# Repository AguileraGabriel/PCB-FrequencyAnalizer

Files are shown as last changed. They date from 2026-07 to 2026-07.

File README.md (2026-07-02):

# TD3-FrequencyAnalizer

Proyecto de KiCad para el Analizador de Frecuencias (TD3).

## Descripción del Proyecto

Este es un proyecto de diseño de PCB desarrollado en KiCad 10.0.4.

## Estructura del Proyecto

*   **`TD3-FrequencyAnalizer.kicad_pro`**: Archivo de proyecto de KiCad.
*   **`TD3-FrequencyAnalizer.kicad_sch`**: Esquema del circuito.
*   **`TD3-FrequencyAnalizer.kicad_pcb`**: Diseño del circuito impreso (PCB).
*   **`.gitignore`**: Exclusiones de Git para evitar subir archivos temporales y copias de seguridad de KiCad.

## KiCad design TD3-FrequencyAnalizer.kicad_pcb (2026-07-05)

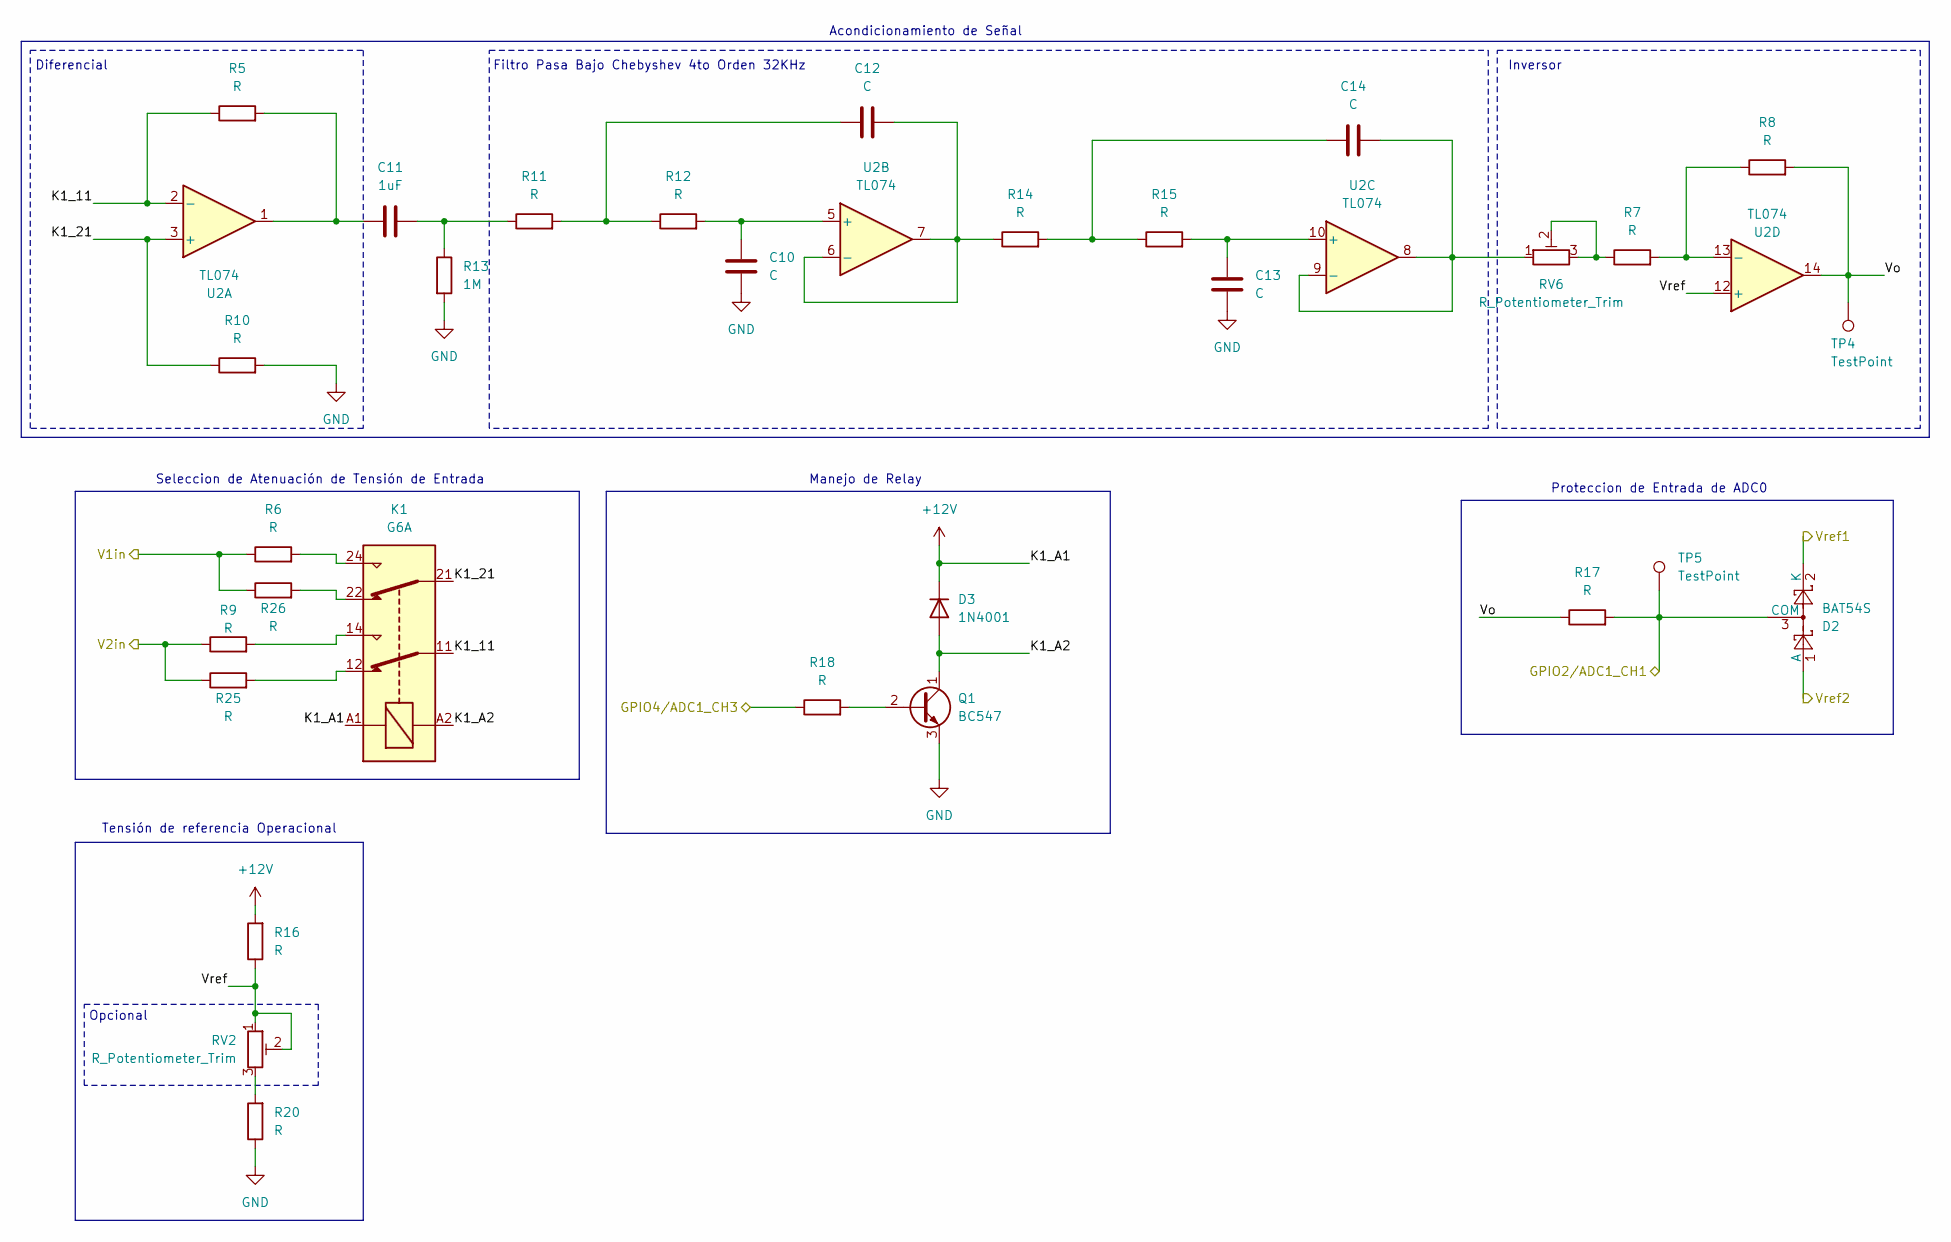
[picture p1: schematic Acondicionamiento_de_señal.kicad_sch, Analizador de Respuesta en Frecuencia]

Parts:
C10, C12, C13, C14: C; C_Disc_D7.5mm_W2.5mm_P5.00mm
C11: 1uF; C_Disc_D7.5mm_W2.5mm_P5.00mm
D2: BAT54S; SOT-23
D3: 1N4001; D_DO-41_SOD81_P10.16mm_Horizontal
K1: G6A; Relay_DPDT_Omron_G6A
Q1: BC547; TO-92_HandSolder
R5, R6, R7, R8, R9, R10, R11, R12, R14, R15, R16, R17, R18, R20, R25, R26: R; R_Axial_DIN0207_L6.3mm_D2.5mm_P10.16mm_Horizontal
R13: 1M; R_Axial_DIN0207_L6.3mm_D2.5mm_P10.16mm_Horizontal
RV2, RV6: R_Potentiometer_Trim; Potentiometer_Bourns_3266Y_Vertical
TP4, TP5: TestPoint; TestPoint_Loop_D2.50mm_Drill1.0mm
U2: TL074; CERDIP-14_W7.62mm_SideBrazed_LongPads_Socket

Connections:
+12V: D3.1 (K), K1.A1, R16.2; also elsewhere on the board
/Acondicionamiento de Señal de Entrada/GPIO2/ADC1_CH1: D2.3 (COM), R17.2, TP5.1 (1_1); also elsewhere on the board
/Acondicionamiento de Señal de Entrada/GPIO4/ADC1_CH3: R18.1; also elsewhere on the board
/Acondicionamiento de Señal de Entrada/K1_11: K1.11, R5.1, U2.2 (-)
/Acondicionamiento de Señal de Entrada/K1_21: K1.21, R10.1, U2.3 (+)
/Acondicionamiento de Señal de Entrada/K1_A2: D3.2 (A), K1.A2, Q1.1 (C)
/Acondicionamiento de Señal de Entrada/V1in: R6.1, R26.1; also elsewhere on the board
/Acondicionamiento de Señal de Entrada/V2in: R9.1, R25.1; also elsewhere on the board
/Acondicionamiento de Señal de Entrada/Vo: R8.2, R17.1, TP4.1 (1_1), U2.14
/Acondicionamiento de Señal de Entrada/Vref: R16.1, RV2.1, RV2.2, U2.12 (+)
/Acondicionamiento de Señal de Entrada/Vref1: D2.2 (K); also elsewhere on the board
/Acondicionamiento de Señal de Entrada/Vref2: D2.1 (A); also elsewhere on the board
GND: C10.2, C13.2, Q1.3 (E), R10.2, R13.2, R20.1; also elsewhere on the board
unnamed: C11.1, R5.2, U2.1
unnamed: C11.2, R11.1, R13.1
unnamed: C12.1, R11.2, R12.1
unnamed: C14.1, R14.2, R15.1
unnamed: K1.12, R25.2
unnamed: K1.14, R9.2
unnamed: K1.22, R26.2
unnamed: K1.24, R6.2
unnamed: Q1.2 (B), R18.2
unnamed: R7.1, RV6.2, RV6.3
unnamed: R20.2, RV2.3
unnamed: C10.1, R12.2, U2.5 (+)
unnamed: C12.2, R14.1, U2.6 (-), U2.7
unnamed: C13.1, R15.2, U2.10 (+)
unnamed: C14.2, RV6.1, U2.8, U2.9 (-)
unnamed: R7.2, R8.1, U2.13 (-)

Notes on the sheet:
Manejo de Relay
Opcional
Filtro Pasa Bajo Chebyshev 4to Orden 32KHz
Acondicionamiento de Señal
Seleccion de Atenuación de Tensión de Entrada
Diferencial
Tensión de referencia Operacional
Proteccion de Entrada de ADC0
Inversor

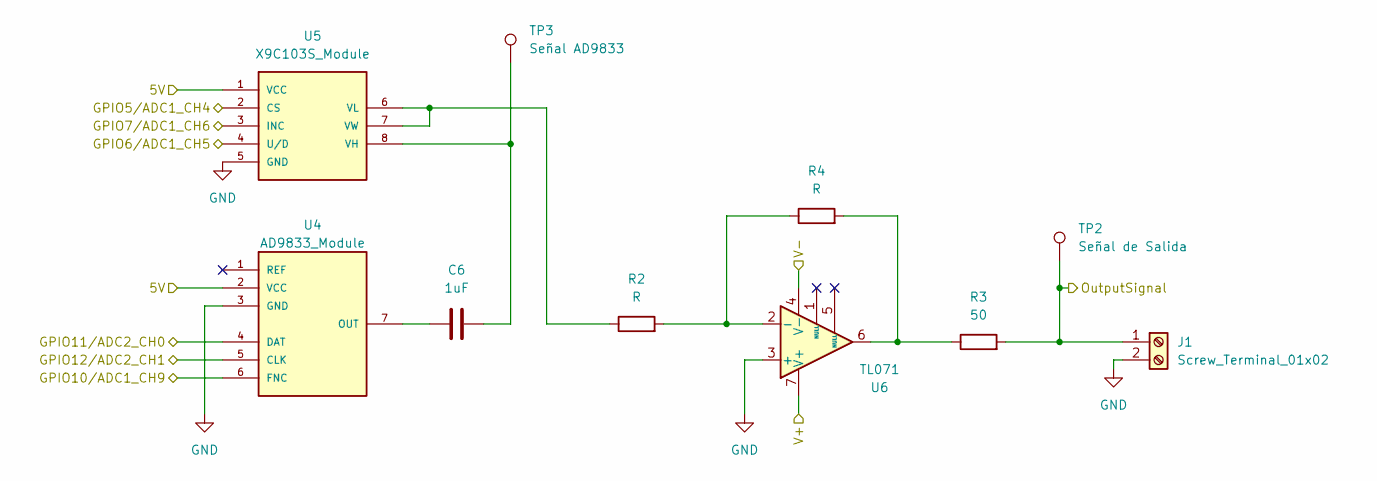
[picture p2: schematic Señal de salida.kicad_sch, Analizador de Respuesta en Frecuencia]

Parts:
C6: 1uF; C_Disc_D7.5mm_W2.5mm_P5.00mm
J1: Screw_Terminal_01x02; TerminalBlock_MaiXu_MX126-5.0-02P_1x02_P5.00mm
R2, R4: R; R_Axial_DIN0207_L6.3mm_D2.5mm_P10.16mm_Horizontal
R3: 50; R_Axial_DIN0207_L6.3mm_D2.5mm_P10.16mm_Horizontal
TP2: Señal de Salida; TestPoint_Loop_D2.50mm_Drill1.0mm
TP3: Señal AD9833; TestPoint_Loop_D2.50mm_Drill1.0mm
U4: AD9833_Module
U5: X9C103S_Module
U6: TL071; CERDIP-8_W7.62mm_SideBrazed_LongPads_Socket

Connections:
+12V: U6.7 (V+); also elsewhere on the board
-12V: U6.4 (V-); also elsewhere on the board
/ESP32-S3/5V: U4.2 (VCC), U5.1 (VCC); also elsewhere on the board
/ESP32-S3/GPIO5/ADC1_CH4: U5.2 (CS); also elsewhere on the board
/ESP32-S3/GPIO6/ADC1_CH5: U5.4 (U/D); also elsewhere on the board
/ESP32-S3/GPIO7/ADC1_CH6: U5.3 (INC); also elsewhere on the board
/ESP32-S3/GPIO10/ADC1_CH9: U4.6 (FNC); also elsewhere on the board
/ESP32-S3/GPIO11/ADC2_CH0: U4.4 (DAT); also elsewhere on the board
/ESP32-S3/GPIO12/ADC2_CH1: U4.5 (CLK); also elsewhere on the board
/Medición de Señal Inyectada/OutputSignal: J1.1, R3.2, TP2.1 (1_1); also elsewhere on the board
GND: J1.2, U4.3 (GND), U5.5 (GND), U6.3 (+); also elsewhere on the board
unnamed: R3.1, R4.2, U6.6
unnamed: C6.1, U4.7 (OUT)
unnamed: C6.2, TP3.1 (1_1), U5.8 (VH)
unnamed: R2.1, U5.6 (VL), U5.7 (VW)
unnamed: R2.2, R4.1, U6.2 (-)

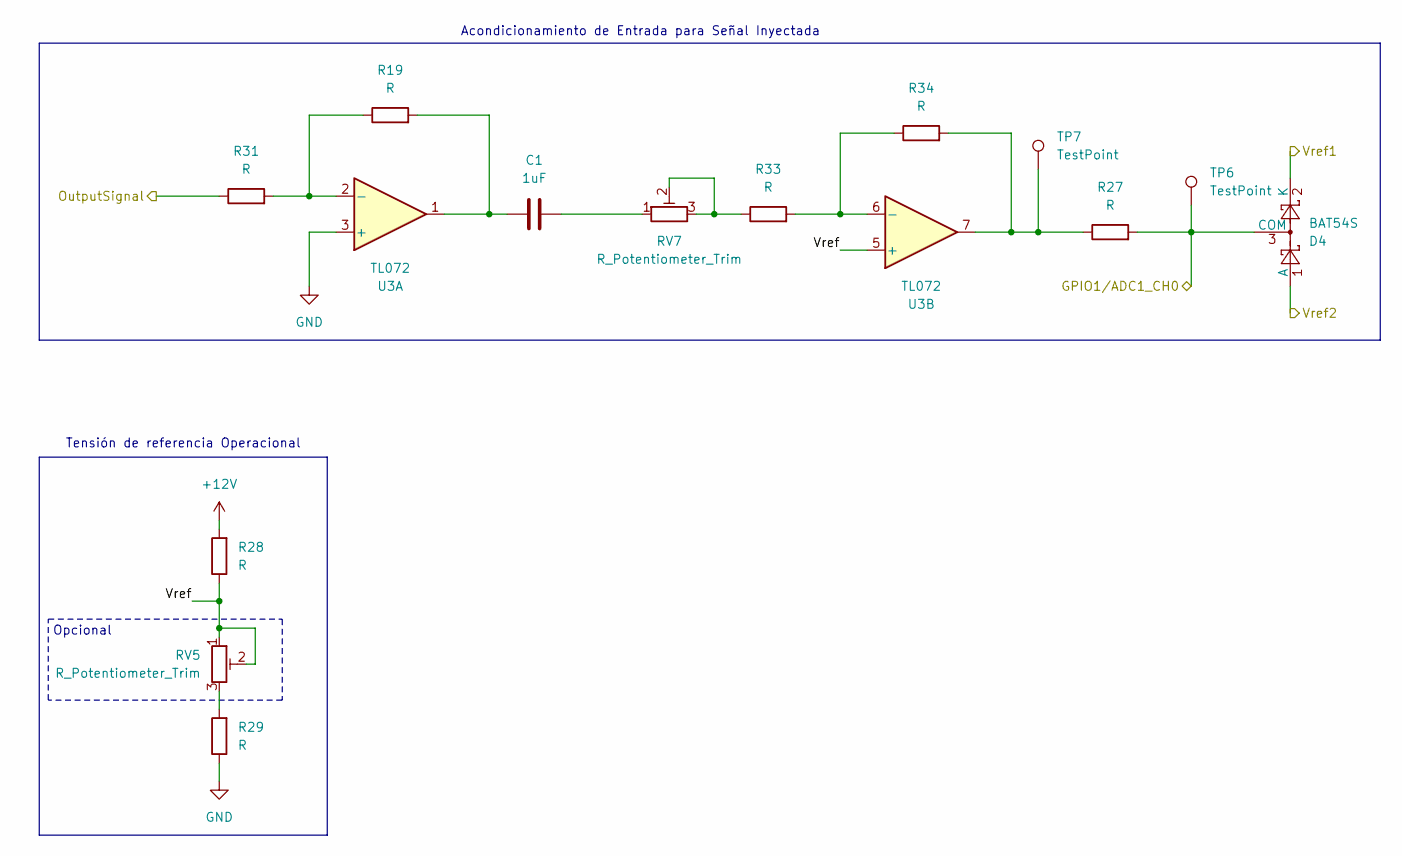
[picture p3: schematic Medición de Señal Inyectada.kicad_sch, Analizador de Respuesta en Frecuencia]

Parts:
C1: 1uF; C_Disc_D7.5mm_W2.5mm_P5.00mm
D4: BAT54S; SOT-23
R19, R27, R28, R29, R31, R33, R34: R; R_Axial_DIN0207_L6.3mm_D2.5mm_P10.16mm_Horizontal
RV5, RV7: R_Potentiometer_Trim; Potentiometer_Bourns_3266Y_Vertical
TP6, TP7: TestPoint; TestPoint_Loop_D2.50mm_Drill1.0mm
U3: TL072; CERDIP-8_W7.62mm_SideBrazed_LongPads_Socket

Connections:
+12V: R28.2; also elsewhere on the board
/Acondicionamiento de Señal de Entrada/Vref1: D4.2 (K); also elsewhere on the board
/Acondicionamiento de Señal de Entrada/Vref2: D4.1 (A); also elsewhere on the board
/ESP32-S3/GPIO1/ADC1_CH0: D4.3 (COM), R27.2, TP6.1 (1_1); also elsewhere on the board
/Medición de Señal Inyectada/OutputSignal: R31.1; also elsewhere on the board
/Medición de Señal Inyectada/Vref: R28.1, RV5.1, RV5.2, U3.5 (+)
GND: R29.1, U3.3 (+); also elsewhere on the board
unnamed: C1.1, R19.2, U3.1
unnamed: C1.2, RV7.1
unnamed: R27.1, R34.2, TP7.1 (1_1), U3.7
unnamed: R29.2, RV5.3
unnamed: R33.1, RV7.2, RV7.3
unnamed: R19.1, R31.2, U3.2 (-)
unnamed: R33.2, R34.1, U3.6 (-)

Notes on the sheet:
Opcional
Acondicionamiento de Entrada para Señal Inyectada
Tensión de referencia Operacional

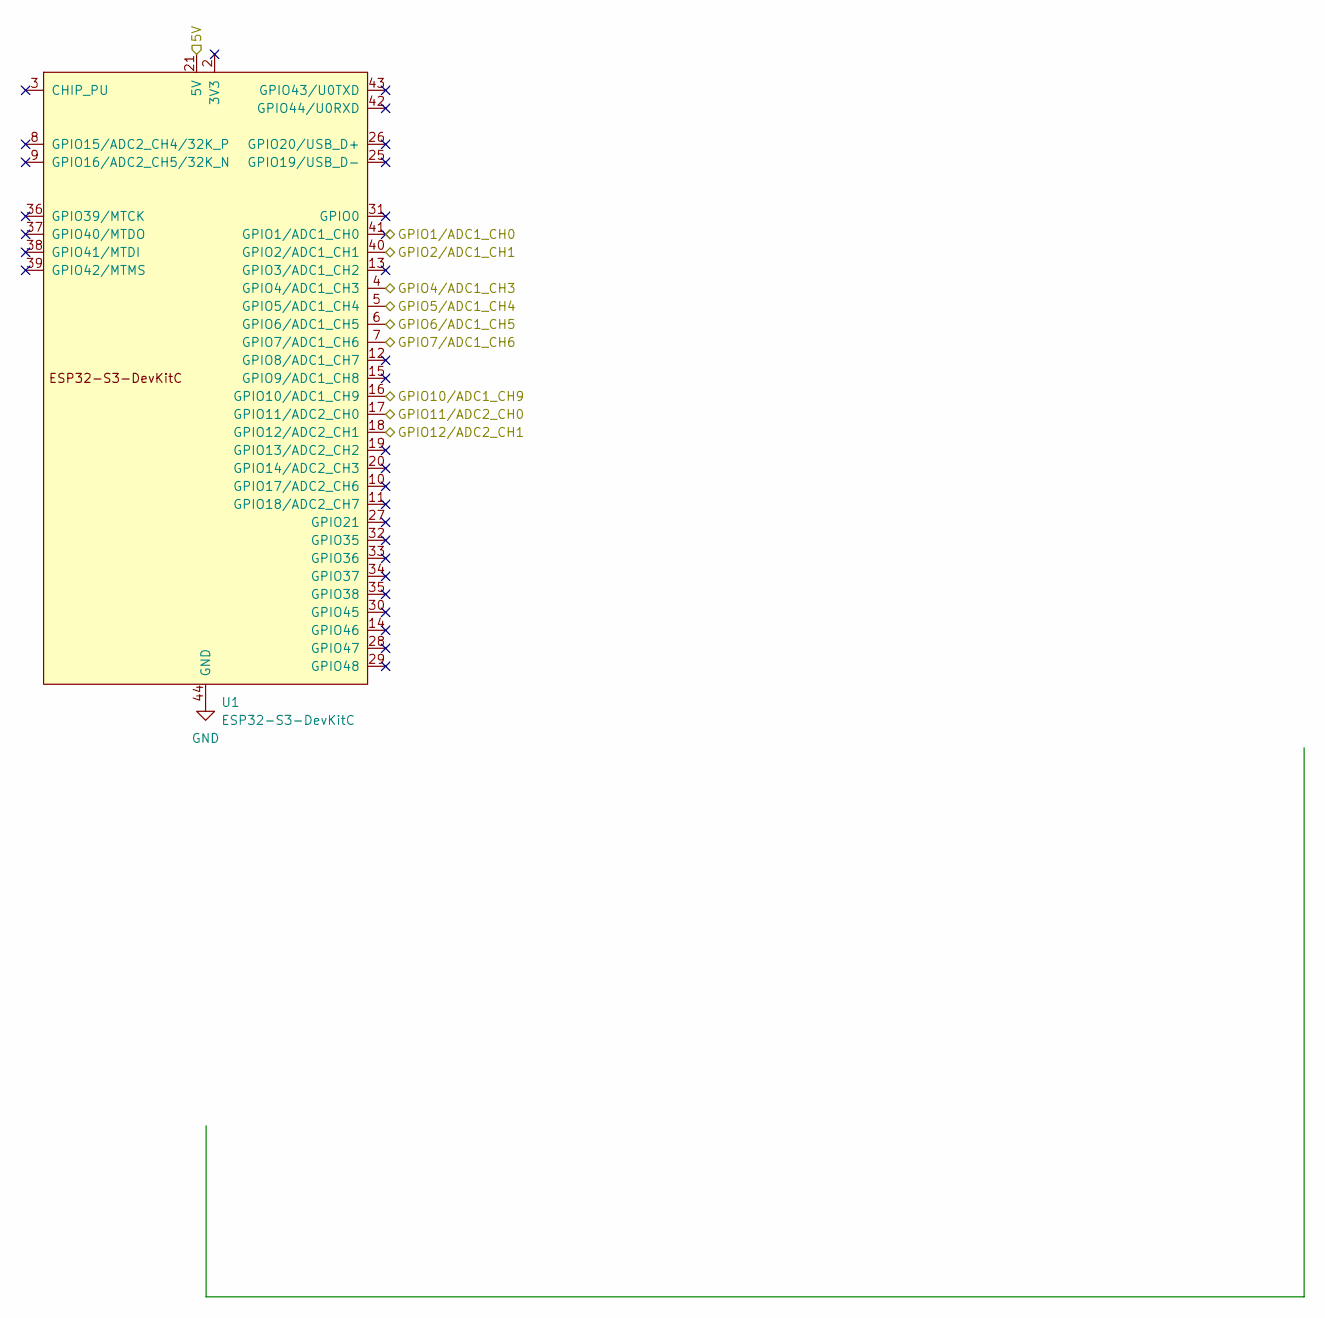
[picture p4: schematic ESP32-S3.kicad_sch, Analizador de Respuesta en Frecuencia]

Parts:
U1: ESP32-S3-DevKitC

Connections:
/Acondicionamiento de Señal de Entrada/GPIO2/ADC1_CH1: U1.40 (GPIO2/ADC1_CH1); also elsewhere on the board
/Acondicionamiento de Señal de Entrada/GPIO4/ADC1_CH3: U1.4 (GPIO4/ADC1_CH3); also elsewhere on the board
/ESP32-S3/5V: U1.21 (5V); also elsewhere on the board
/ESP32-S3/GPIO1/ADC1_CH0: U1.41 (GPIO1/ADC1_CH0); also elsewhere on the board
/ESP32-S3/GPIO5/ADC1_CH4: U1.5 (GPIO5/ADC1_CH4); also elsewhere on the board
/ESP32-S3/GPIO6/ADC1_CH5: U1.6 (GPIO6/ADC1_CH5); also elsewhere on the board
/ESP32-S3/GPIO7/ADC1_CH6: U1.7 (GPIO7/ADC1_CH6); also elsewhere on the board
/ESP32-S3/GPIO10/ADC1_CH9: U1.16 (GPIO10/ADC1_CH9); also elsewhere on the board
/ESP32-S3/GPIO11/ADC2_CH0: U1.17 (GPIO11/ADC2_CH0); also elsewhere on the board
/ESP32-S3/GPIO12/ADC2_CH1: U1.18 (GPIO12/ADC2_CH1); also elsewhere on the board
GND: U1.22 (GND), U1.23 (GND), U1.24 (GND), U1.44 (GND); also elsewhere on the board

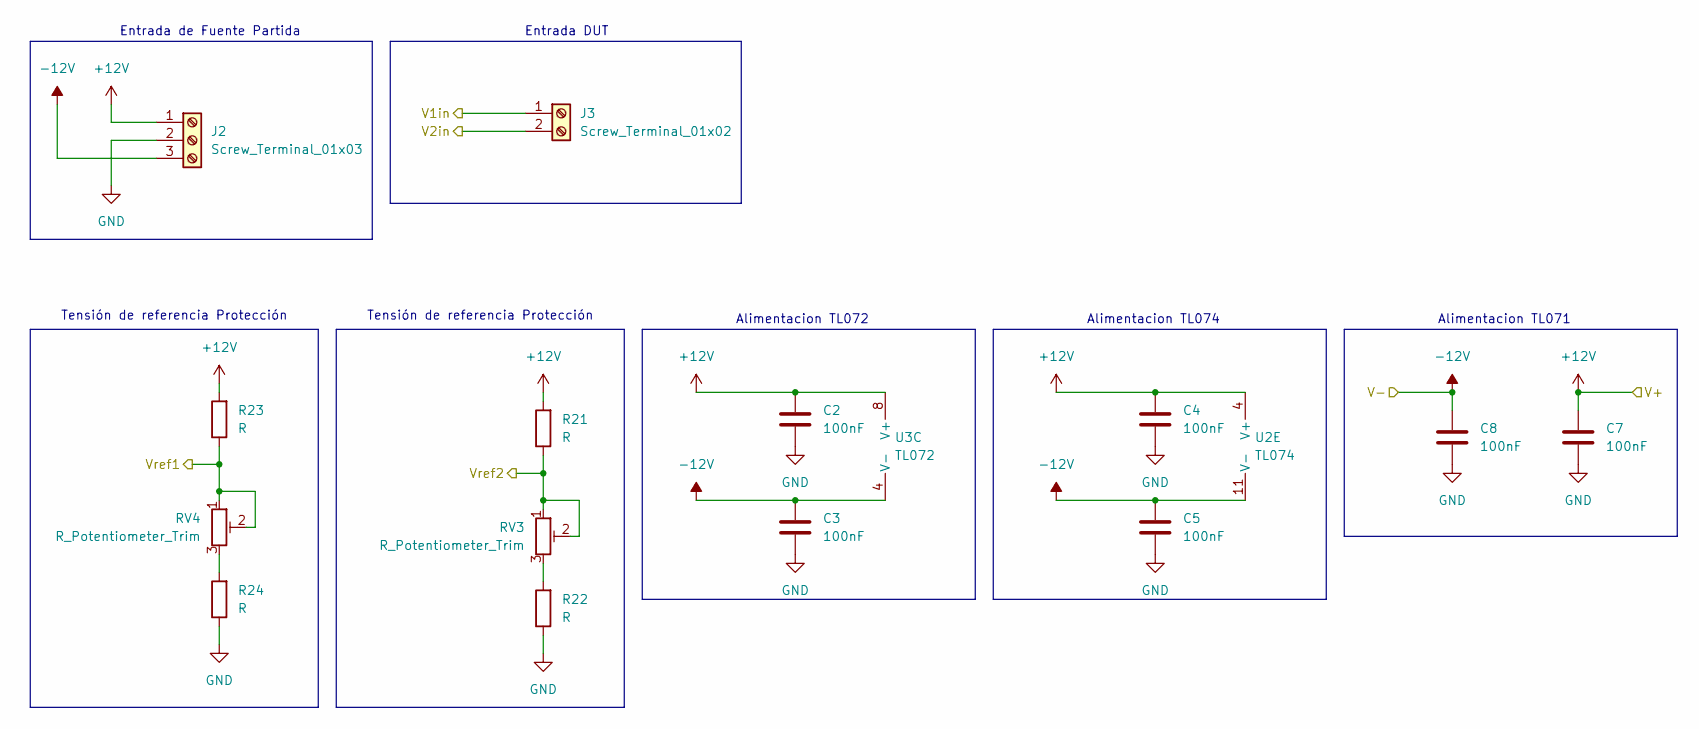
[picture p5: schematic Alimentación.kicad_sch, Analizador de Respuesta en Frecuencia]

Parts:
C2, C3, C4, C5, C7, C8: 100nF; C_Disc_D7.5mm_W2.5mm_P5.00mm
J2: Screw_Terminal_01x03; TerminalBlock_MaiXu_MX126-5.0-03P_1x03_P5.00mm
J3: Screw_Terminal_01x02; TerminalBlock_MaiXu_MX126-5.0-02P_1x02_P5.00mm
R21, R22, R23, R24: R; R_Axial_DIN0207_L6.3mm_D2.5mm_P10.16mm_Horizontal
RV3, RV4: R_Potentiometer_Trim; Potentiometer_Bourns_3266Y_Vertical
U2: TL074; CERDIP-14_W7.62mm_SideBrazed_LongPads_Socket
U3: TL072; CERDIP-8_W7.62mm_SideBrazed_LongPads_Socket

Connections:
+12V: C2.1, C4.1, C7.2, J2.1, R21.2, R23.2, U2.4 (V+), U3.8 (V+); also elsewhere on the board
-12V: C3.1, C5.1, C8.2, J2.3, U2.11 (V-), U3.4 (V-); also elsewhere on the board
/Acondicionamiento de Señal de Entrada/V1in: J3.1; also elsewhere on the board
/Acondicionamiento de Señal de Entrada/V2in: J3.2; also elsewhere on the board
/Acondicionamiento de Señal de Entrada/Vref1: R23.1, RV4.1, RV4.2; also elsewhere on the board
/Acondicionamiento de Señal de Entrada/Vref2: R21.1, RV3.1, RV3.2; also elsewhere on the board
GND: C2.2, C3.2, C4.2, C5.2, C7.1, C8.1, J2.2, R22.1, R24.1; also elsewhere on the board
unnamed: R22.2, RV3.3
unnamed: R24.2, RV4.3

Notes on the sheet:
Alimentacion TL071
Tensión de referencia Protección
Alimentacion TL074
Entrada de Fuente Partida
Alimentacion TL072
Entrada DUT

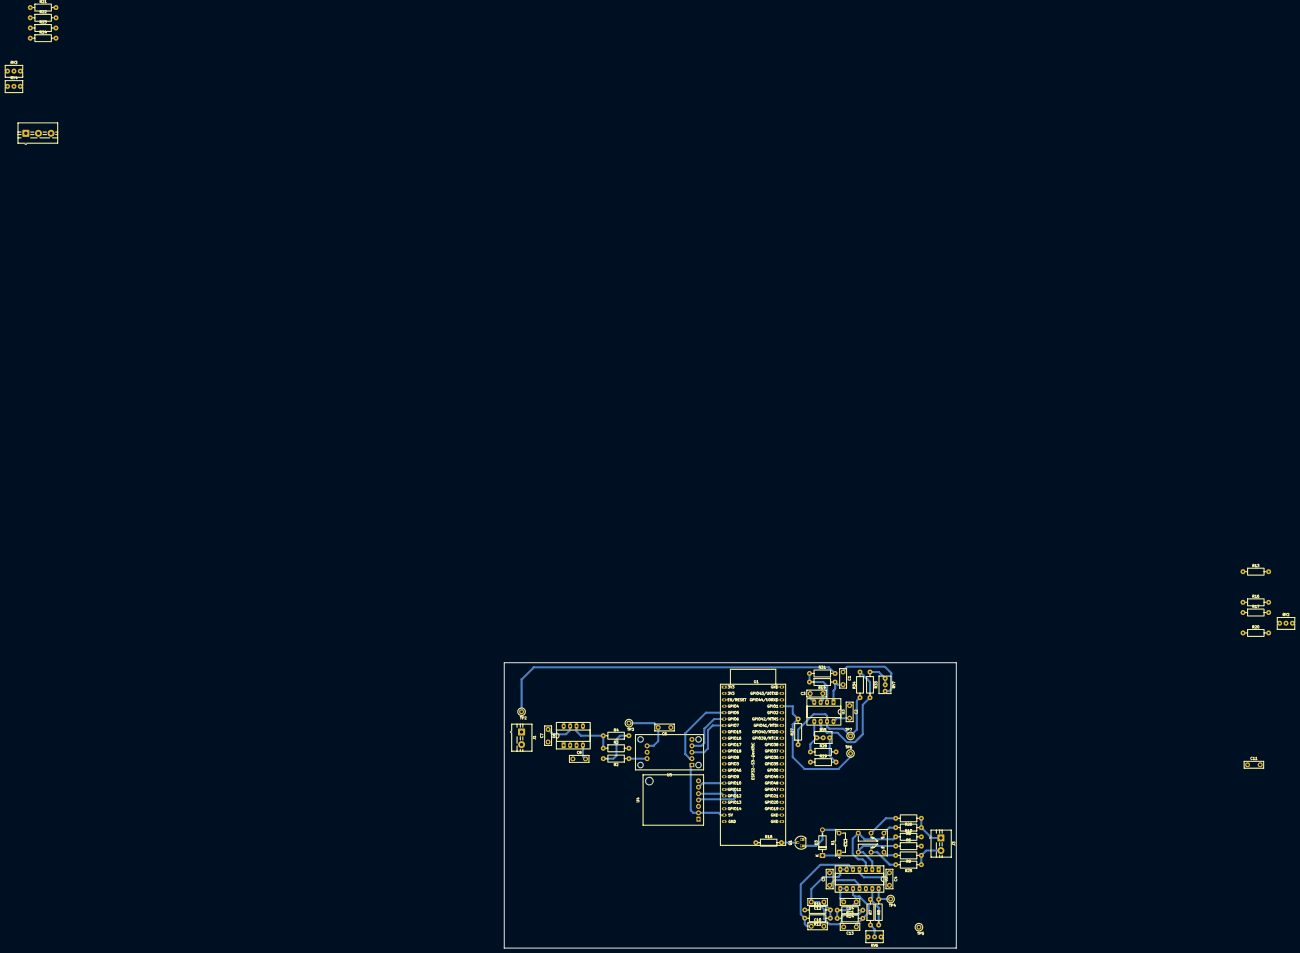
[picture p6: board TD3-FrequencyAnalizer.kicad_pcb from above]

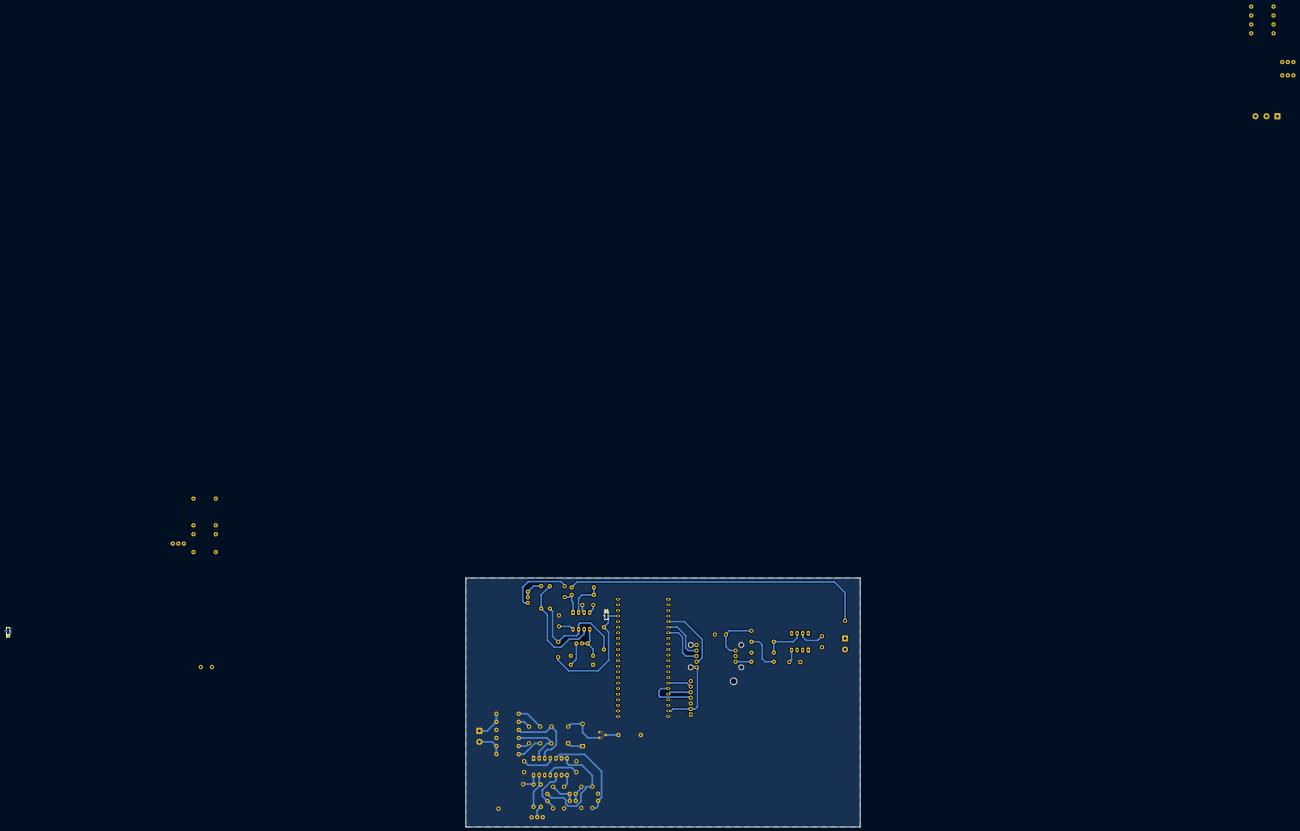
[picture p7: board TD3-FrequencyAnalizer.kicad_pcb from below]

Board: 2 copper layers, 179.3 x 113.2 mm, 70 parts (2 on the bottom side), 54 nets.

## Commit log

2026-07-02 Initial commit: Initialize KiCad 10.0.4 project
    [TD3-FrequencyAnalizer.kicad_pcb, TD3-FrequencyAnalizer.kicad_sch]
2026-07-02 Fix file formatting: Replace literal backtick-n with real newlines
    [TD3-FrequencyAnalizer.kicad_pcb, TD3-FrequencyAnalizer.kicad_sch]
2026-07-03 Update project files and add schematic sheets (ESP32-S3, Alimentacion, Acondicionamiento, Salida)
    [Acondicionamiento_de_señal.kicad_sch, Alimentación.kicad_sch, ESP32-S3.kicad_sch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]
2026-07-05 Update schematics: signal conditioning, power, ESP32-S3, output, and add signal measurement sub-sheet
    [Acondicionamiento_de_señal.kicad_sch, Alimentación.kicad_sch, ESP32-S3.kicad_sch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]
2026-07-05 Save local schematic and board updates before 3D model path resolution
    [Acondicionamiento_de_señal.kicad_sch, Medición de Señal Inyectada.kicad_sch, TD3-FrequencyAnalizer.kicad_pcb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]
2026-07-05 Update PCB layout: Component placements, routing and 3D model alignments
    [TD3-FrequencyAnalizer.kicad_pcb]
